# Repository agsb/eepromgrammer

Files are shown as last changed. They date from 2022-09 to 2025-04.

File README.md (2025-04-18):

# EEprogammer

I need a eeprom programmer for use in my projects and want make one
to learn how to wire-wrap.

## Ideas

Based on projects by 
Ben Eater (https://github.com/beneater/eeprom-programmer),
Dave Hovemayer (https://github.com/daveho/eeprog) and 
Tom Nisbet (https://github.com/TomNisbet/TommyPROM)
but with with hardware support for I2C and SPI eeproms.

From above, the following are ok:
        
        - use a Arduino (nano) as main board, with RST, TX and RX reserved;
        - use two 74HC595 for 16-bit address, one for lower byte address, 
                other for uppper byte addres, not chainned
        - use 5 pins for control the both 74HC595
        - use 8 pins for 8-bit data
        - use 2 pins (SDA, SCL) for I2C, WP, S0, S1, S2 to GND, for I2C
        - use 5 pins (/CS, /HOLD, MSCK, MISO, MOSI), WP to VCC, for SPI

From a arduino mini:
        
        - reserved RXD, TXD 
        - using D2 to D9 as data pins
        - using D9 as /HOLD and D10, D11, D12, D13, as SPI

## Pins map

The first design of eeprogrammer was too sensible to errors in 
dip-switches, overrated usability and complex circuit and software, 
then I simply put more headers for other eeprom families;

The reference [Pinout](https://github.com/agsb/eepromgrammer/blob/148cf59fdfdf9b6ff1b859eb0863042efeae660a/PinsOuts.md)

OBS.

I try K.I.S.S.

For all pull-ups using 4k7 resistors.

For all chips VCC - 100nF - GND

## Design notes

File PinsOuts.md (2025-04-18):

## Header Pin Configuration

| Header Pin | Name | Description |
| --- | --- | --- |
| 7 | A14 | Address Pin 14 | 
| 8 | A12 | Address Pin 12 | 
| 9 | A7 | Address Pin 7 | 
| 10 | A6 | Address Pin 6 | 
| 11 | A5 | Address Pin 5 | 
| 12 | A4 | Address Pin 4 | 
| 13 | A3 | Address Pin 3 | 
| 14 | A2 | Address Pin 2 | 
| 15 | A1 | Address Pin 1 | 
| 16 | A0 | Address Pin 0 | 
| 17 | I/O 0 | Data Inputs/Outputs 0 | 
| 18 | I/O 1 | Data Inputs/Outputs 1 | 
| 19 | I/O 2 | Data Inputs/Outputs 2 | 
| 20 | GND | Ground Pin | 

| Header Pin | Name | Description |
| --- | --- | --- |
| 21 | I/O 3 | Data Inputs/Outputs 3 | 
| 22 | I/O 4 | Data Inputs/Outputs 4 | 
| 23 | I/O 5 | Data Inputs/Outputs 5 | 
| 24 | I/O 6 | Data Inputs/Outputs 6 | 
| 25 | I/O 7 | Data Inputs/Outputs 7 | 
| 26 | CE’ | Chip Enable Pin | 
| 27 | A10 | Address Pin 10 | 
| 28 | OE’ | Output Enable | 
| 29 | A11 | Address Pin 11 | 
| 30 | A9 | Address Pin 9 | 
| 31 | A8 | Address Pin 8 | 
| 32 | A13 | Address Pin 13 | 
| 33 | WE’ | Write Enable Pin | 
| 34 | VCC | Supply Voltage Pin | 
| | | |

## Arduino Pin Configuration

| Arduino Pin| circuit | OBS |
| --- | --- | --- |
| D0 | RX | NC, reserved for USART/USB |
| D1 | TX | NC, reserved for USART/USB |
| D2 | D0 | data pin d0 |
| D3 | D1 | data pin d1 |
| D4 | D2 | data pin d2 |
| D5 | D3 | data pin d3 |
| D6 | D4 | data pin d4 |
| D7 | D5 | data pin d5 |
| D8 | D6 | data pin d6 |
| D9 | D7 /HOLD| data pin d7 and SPI /HOLD|
| D10 | /SS RCLK | SPI chip select and serial clock in 74hc595 lower and upper address |
| D11 | MOSI D15 | SPI mosi and extra high address |
| D12 | MISO D16 | SPI miso and extra high address |
| D13 | SCK  D17 | SPI msck and extra high address |
| GND | VSS | board GND |

| Arduino Pin | circuit | OBS |
| --- | --- | --- |
| A0 | /CE | Chip Enable  |
| A1 | /WE | Write Enable |
| A2 | /OE | Output Enable |
| A3 | SRCLR.L | serial clear in 74HC595 lower addres |
| A4 | SDA SRCLR.U | I2C data and serial clear in 74HC595 upper addres |
| A5 | SCL SER.L SER.U | I2C clock and serial in 74HC595 (lower and upper) |

## Pinouts

[Arduino-Nano](https://github.com/agsb/eepromgrammer/blob/e9341a52fbe5ec78b4a520b02f17155613d26bcb/pinout-Arduino-Nano.png)

[SN74HC595](https://github.com/agsb/eepromgrammer/blob/b177c6ecdc0a47e471f062eab4fed304ac8fa284/pinout-74hc595.png)

[AT28C256](https://github.com/agsb/eepromgrammer/blob/e9341a52fbe5ec78b4a520b02f17155613d26bcb/pinout-AT28C256.jpg)

[AT28C64](https://github.com/agsb/eepromgrammer/blob/e9341a52fbe5ec78b4a520b02f17155613d26bcb/pinout-AT28C64.jpg)

[AT28C16](https://github.com/agsb/eepromgrammer/blob/e9341a52fbe5ec78b4a520b02f17155613d26bcb/pinout-AT28C16.png)

[SST39SF040](https://github.com/agsb/eepromgrammer/blob/e9341a52fbe5ec78b4a520b02f17155613d26bcb/pinout-SST39SF040.png)

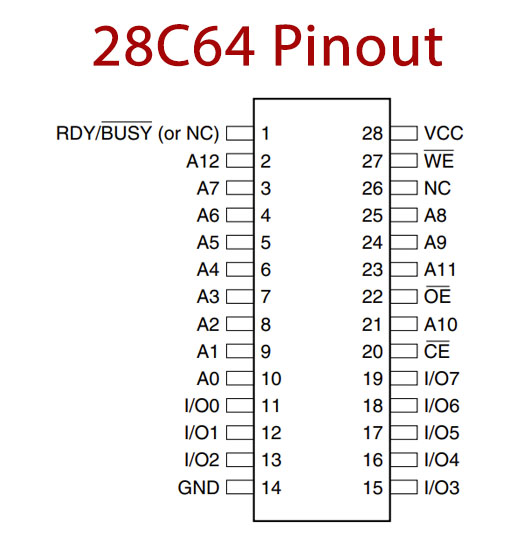
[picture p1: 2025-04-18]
pinout-AT28C64.jpg

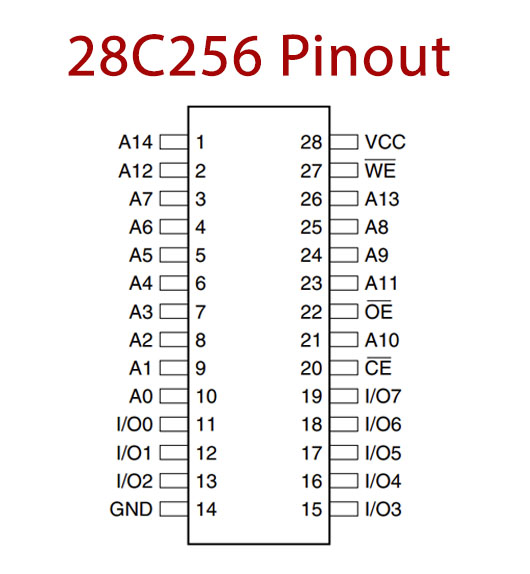
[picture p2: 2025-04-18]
pinout-AT28C256.jpg

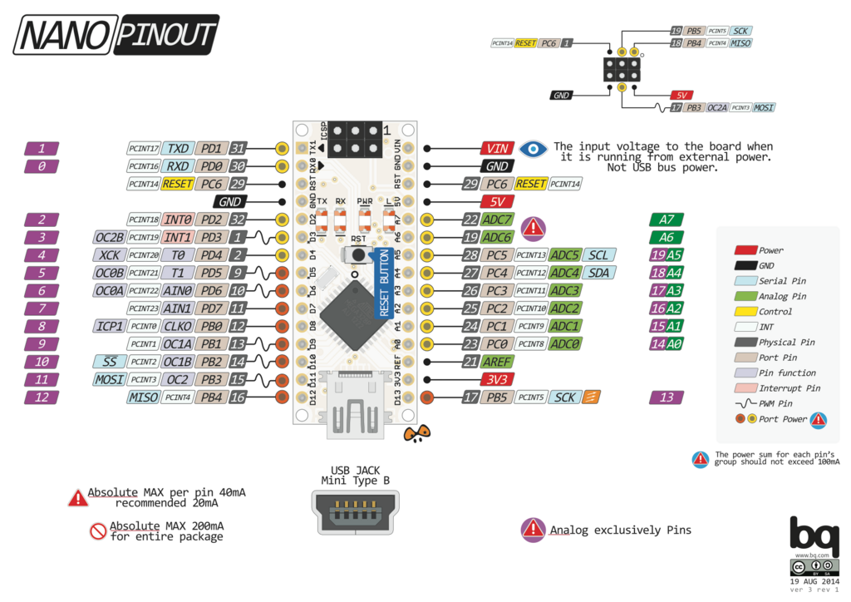
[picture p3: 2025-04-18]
pinout-Arduino-Nano.png

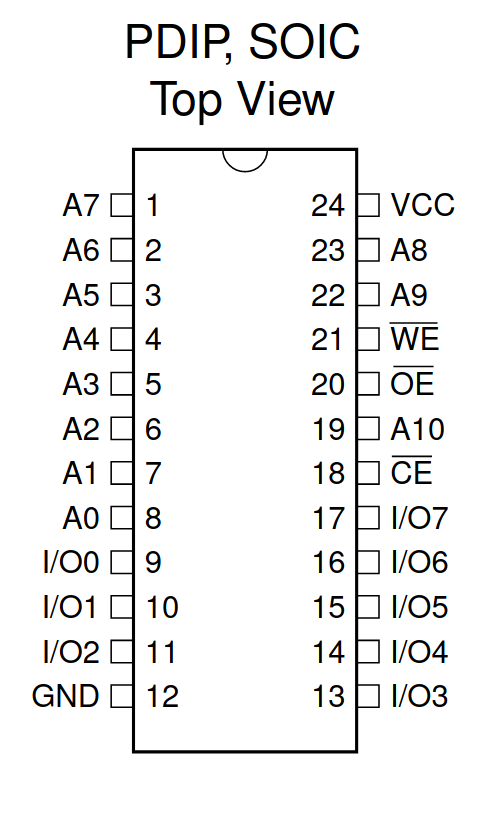
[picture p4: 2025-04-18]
pinout-AT28C16.png

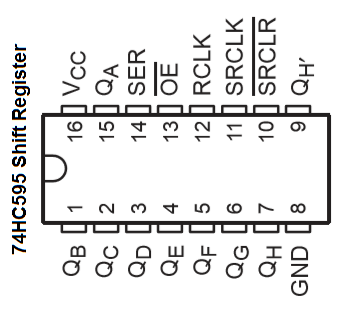
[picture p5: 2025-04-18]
pinout-74hc595.png

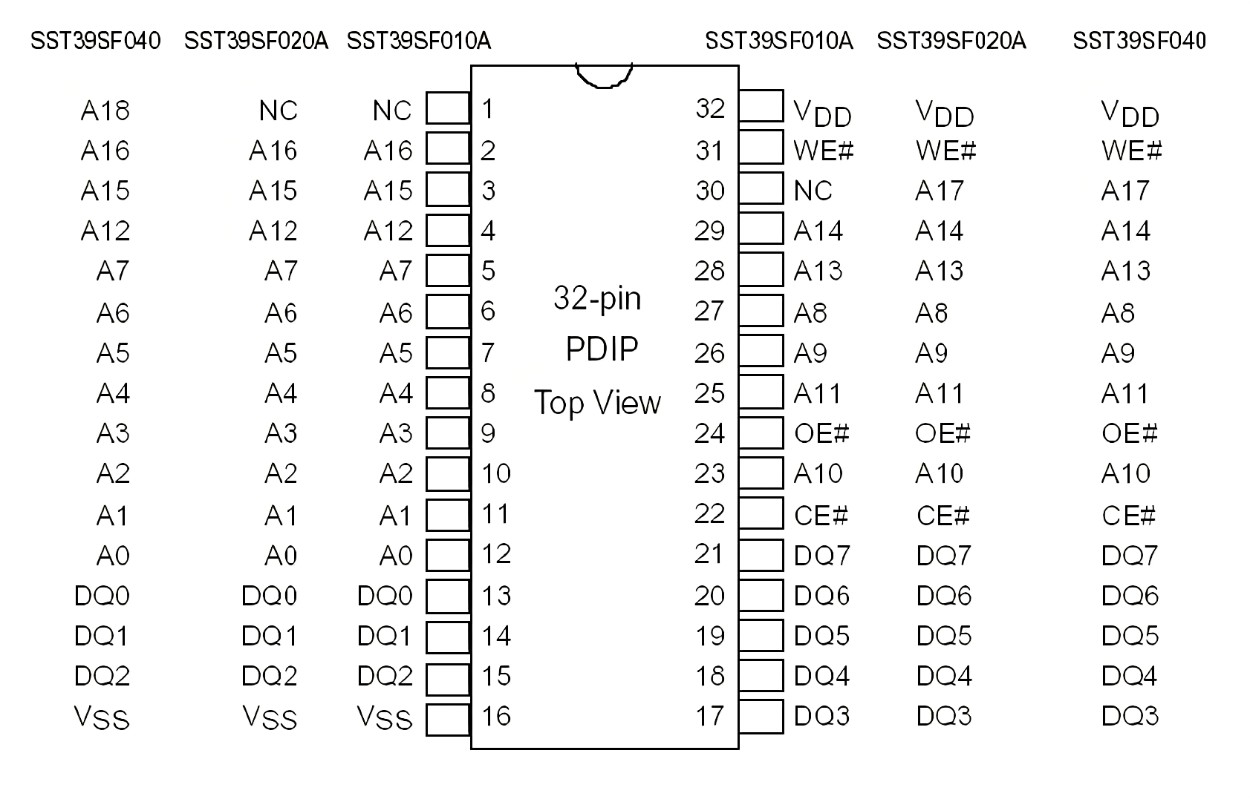
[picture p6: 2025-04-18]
pinout-SST39SF040.png

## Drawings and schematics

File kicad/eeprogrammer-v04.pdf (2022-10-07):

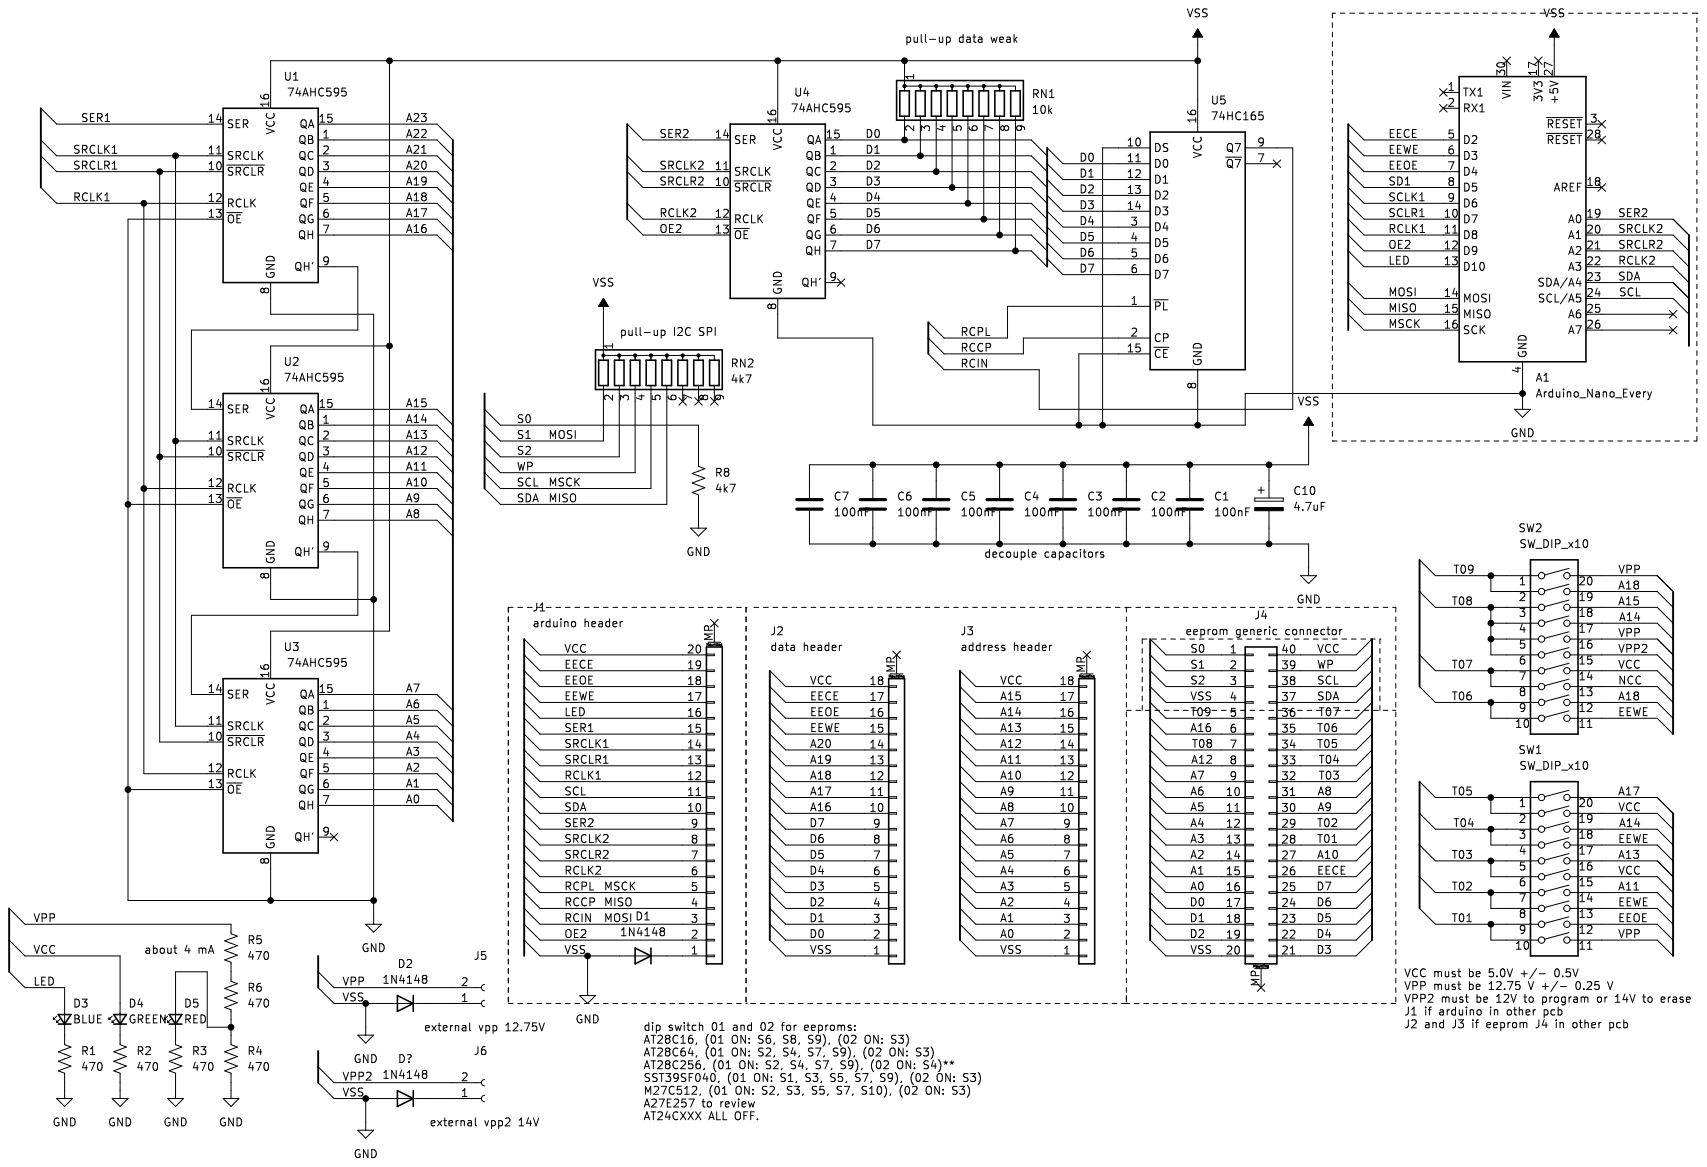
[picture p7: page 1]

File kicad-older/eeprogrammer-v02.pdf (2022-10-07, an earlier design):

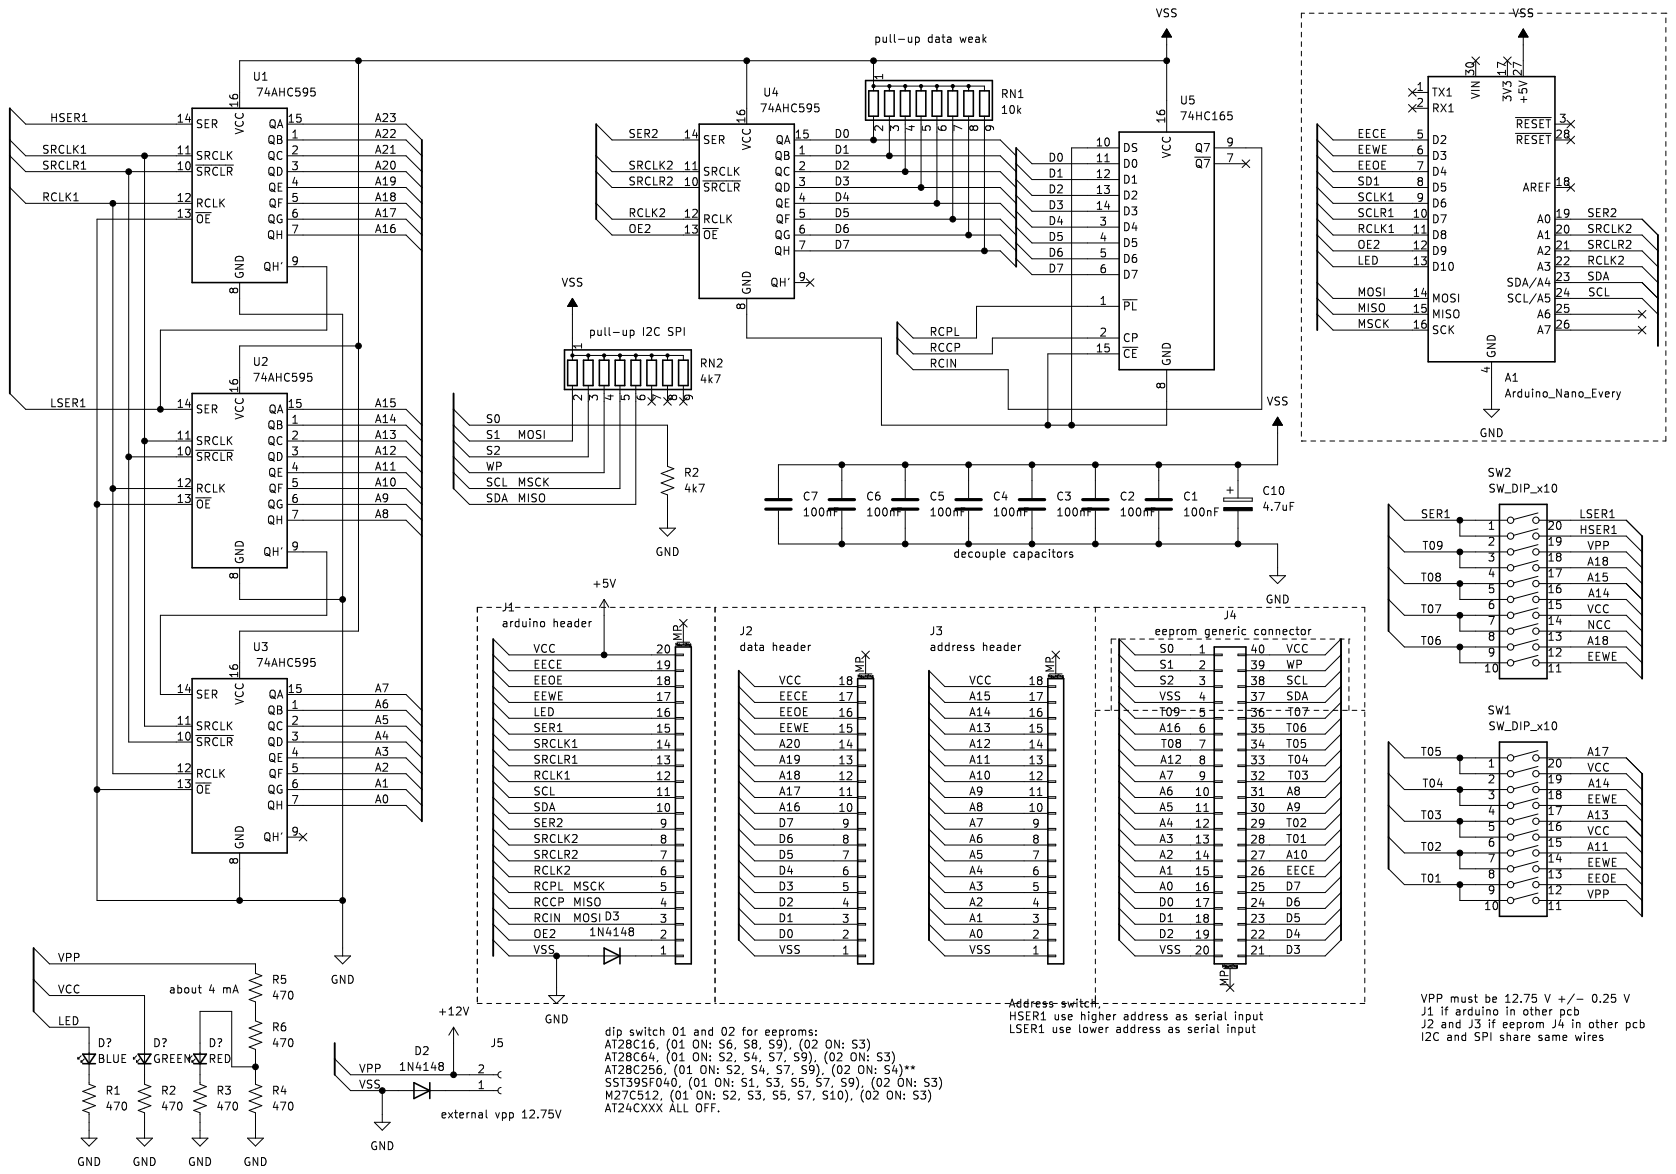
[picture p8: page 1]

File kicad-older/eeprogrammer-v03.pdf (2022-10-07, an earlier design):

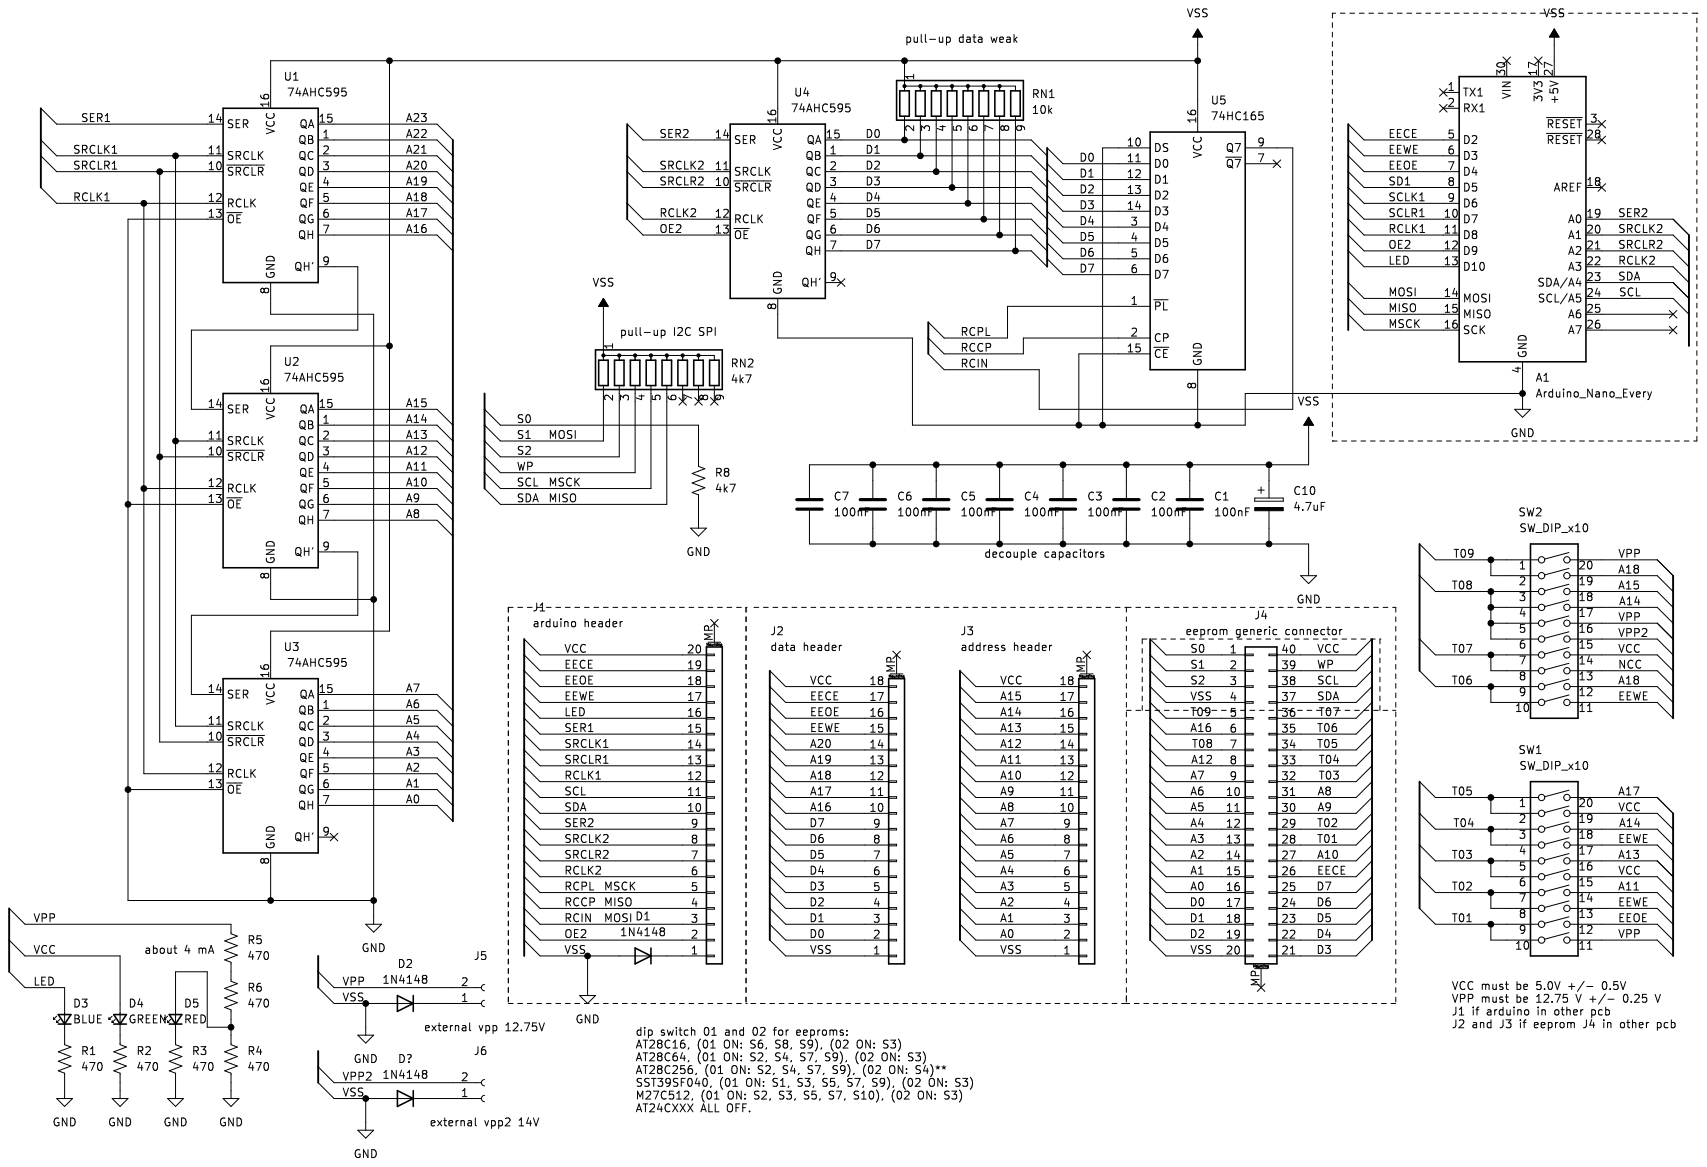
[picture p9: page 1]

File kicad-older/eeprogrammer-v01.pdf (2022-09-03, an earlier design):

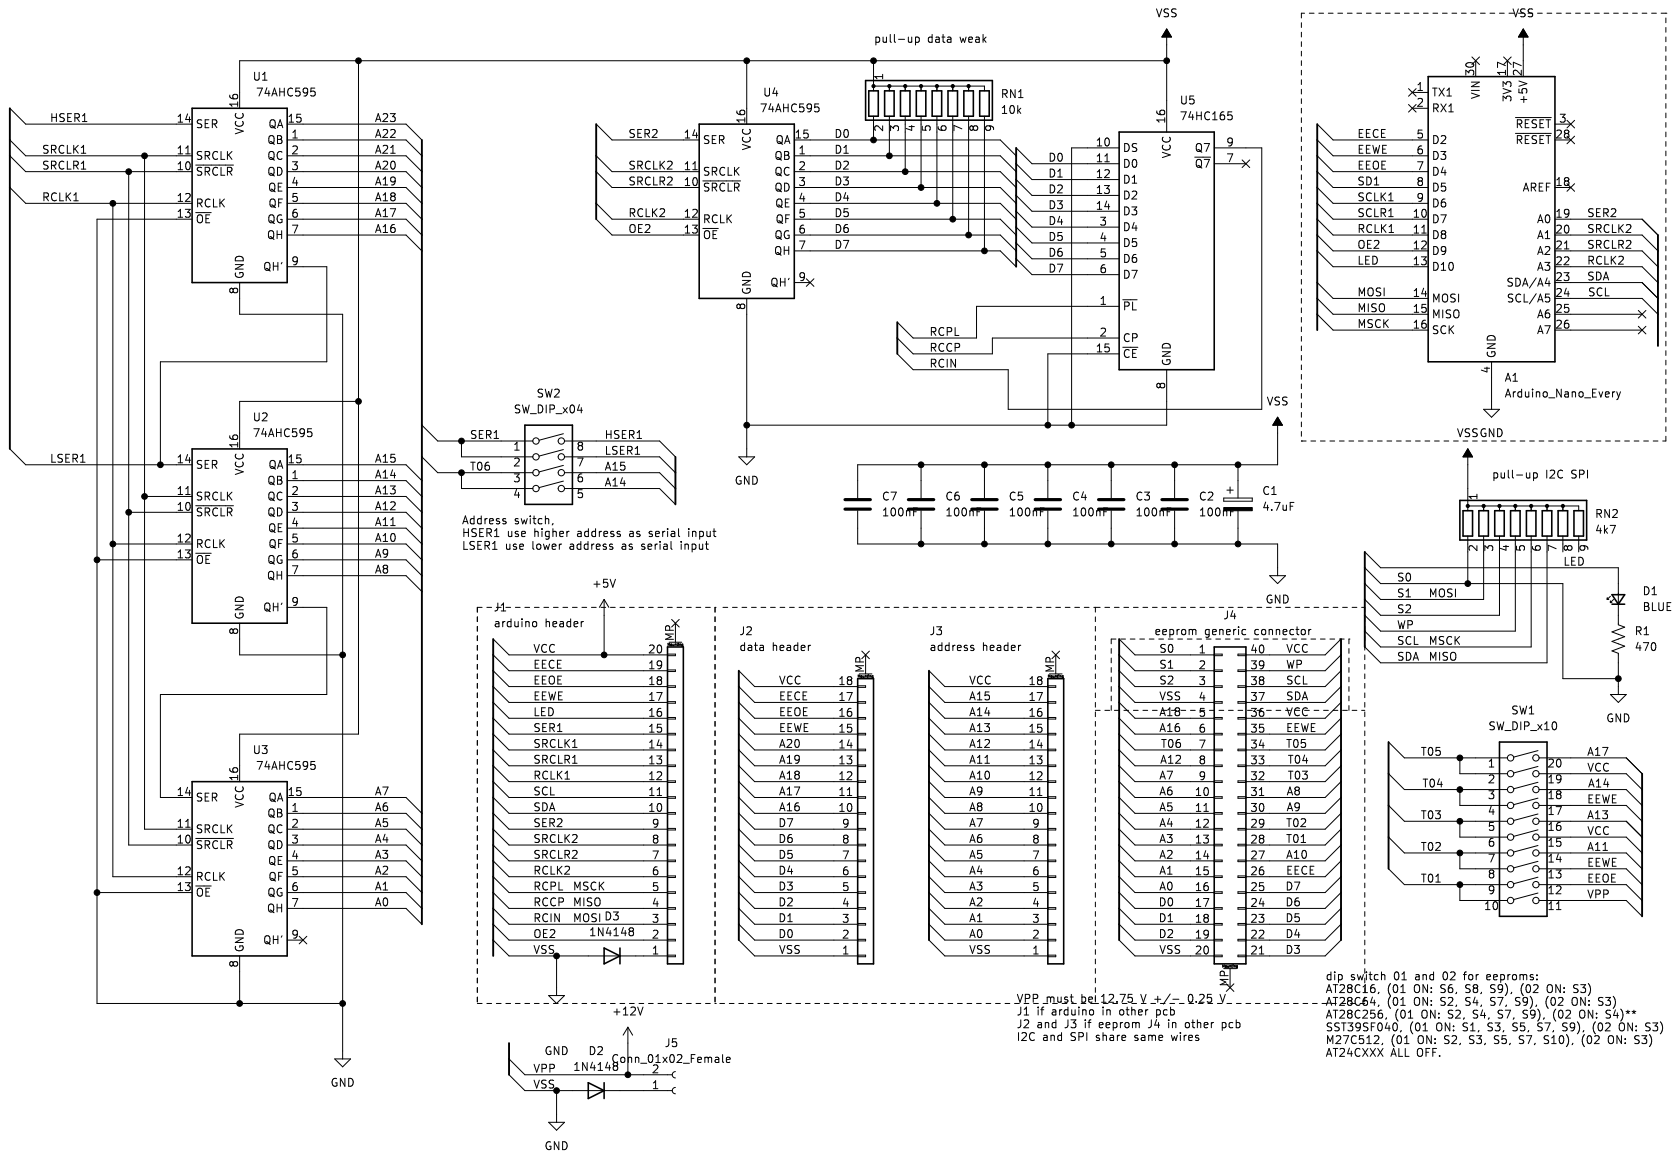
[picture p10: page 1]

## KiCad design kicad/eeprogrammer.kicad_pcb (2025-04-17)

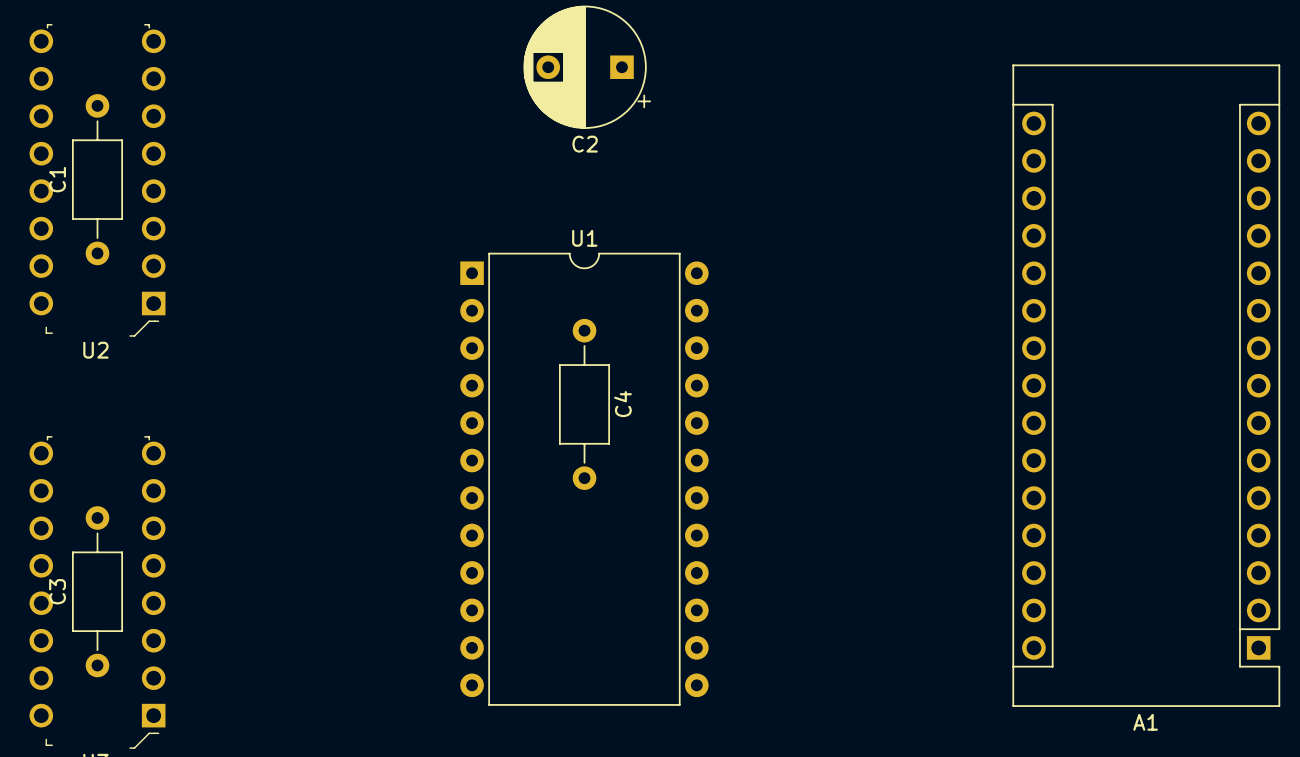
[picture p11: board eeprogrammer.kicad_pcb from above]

Board: 2 copper layers, 8 parts (0 on the bottom side), 30 nets, no tracks yet.

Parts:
A1: Arduino_Nano_v2.x; Arduino_Nano
C1, C3, C4: C; C_Axial_L5.1mm_D3.1mm_P10.00mm_Horizontal
C2: C_Polarized; CP_Radial_D8.0mm_P5.00mm
U1: 28C16; DIP-24_W15.24mm
U2, U3: 74HC595; DIP-16_W7.62mm

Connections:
GND: A1.4 (GND), A1.29 (GND), C1.2, C2.2, C3.2, C4.2, U1.12 (GND), U2.8 (GND), U3.8 (GND)
unnamed: A1.5 (D2), U1.9 (D0)
unnamed: A1.6 (D3), U1.10 (D1)
unnamed: A1.7 (D4), U1.11 (D2)
unnamed: A1.8 (D5), U1.13 (D3)
unnamed: A1.9 (D6), U1.14 (D4)
unnamed: A1.10 (D7), U1.15 (D5)
unnamed: A1.11 (D8), U1.16 (D6)
unnamed: A1.12 (D9), U1.17 (D7)
unnamed: A1.13 (D10), U1.18 (~CS)
unnamed: A1.14 (D11), U1.20 (~OE)
unnamed: A1.15 (D12), U1.21 (~WE)
unnamed: A1.19 (A0), U2.14 (SER)
unnamed: A1.20 (A1), U2.11 (SRCLK), U3.11 (SRCLK)
unnamed: A1.21 (A2), U2.10 (~SRCLR), U3.10 (~SRCLR)
unnamed: A1.22 (A3), U2.12 (RCLK), U3.12 (RCLK)
unnamed: A1.23 (A4), U2.13 (~OE), U3.13 (~OE)
unnamed: U1.7 (A1), U2.1 (QB)
unnamed: U1.6 (A2), U2.2 (QC)
unnamed: U1.5 (A3), U2.3 (QD)
unnamed: U1.4 (A4), U2.4 (QE)
unnamed: U1.3 (A5), U2.5 (QF)
unnamed: U1.2 (A6), U2.6 (QG)
unnamed: U1.1 (A7), U2.7 (QH)
unnamed: U2.9 (QH'), U3.14 (SER)
unnamed: U1.8 (A0), U2.15 (QA)
unnamed: U1.19 (A10), U3.2 (QC)
unnamed: U1.22 (A9), U3.1 (QB)
unnamed: U1.23 (A8), U3.15 (QA)
VCC: A1.27 (+5V), C1.1, C2.1, C3.1, C4.1, U1.24 (VCC), U2.16 (VCC), U3.16 (VCC)

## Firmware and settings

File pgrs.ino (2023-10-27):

/**
 * ** project Arduino EEPROM programmer **
 * 
 * This sketch can be used to read and write data to a
 * AT28C64 or AT28C256 parallel EEPROM
 *
 * $Author: mario, edited by Zack $
 * $Date: 2013/05/05 11:01:54 $
 * $Revision: 1.3 $
 *
 * This software is freeware and can be modified, reused or thrown away without any restrictions.
 *
 * Use this code at your own risk. I'm not responsible for any bad effect or damages caused by this software!!!
 *
 **/

#define VERSIONSTRING "MEEPROMMER $Revision: 1.3 $ $Date: 12/18/2013 15:56:00 $, CMD:R,r,w,W,V, u"

// shiftOut part
#define PORTC_DS      0
#define PORTC_LATCH   1
#define PORTC_CLOCK   2

// eeprom IO lines:D0-D7 = pins2-9

// IO lines for the eeprom control
#define PORTC_CE   3
#define PORTC_OE   4
#define PORTC_WE   5

//a buffer for bytes to burn
#define BUFFERSIZE 1024 
byte buffer[BUFFERSIZE];
//command buffer for parsing commands
#define COMMANDSIZE 16
char cmdbuf[COMMANDSIZE];

unsigned int startAddress,endAddress;
unsigned int lineLength,dataLength;

//define COMMANDS
#define NOCOMMAND    0
#define VERSION      1

#define READ_HEX    10
#define READ_BIN    11

#define WRITE_PAGE  20
#define WRITE_BIN   21

#define UNLOCK      30

/*****************************************************************
 *
 *  CONTROL and DATA functions
 *
 ****************************************************************/

void data_bus_input(){
  DDRD &= 0b00000011;
  DDRB &= 0b11111100;
}

void data_bus_output(){
  DDRD |= 0b11111100;
  DDRB |= 0b00000011;
}

byte read_data_bus(){
  return ((PINB<<6)|(PIND>>2));
}

void write_data_bus(byte data){
  PORTB &= 0b11111100;  
  PORTB |= (data>>6);
  PORTD &= 0b00000011;
  PORTD |= (data<<2);
}

//shift out the given address to the 74hc595 registers
void set_address_bus(unsigned int address){
  bitClear(PORTC,PORTC_LATCH);		//disable latch line
  fastShiftOut(highByte(address));	//shift out highbyte
  fastShiftOut(lowByte(address));	//shift out lowbyte
  bitSet(PORTC,PORTC_LATCH);		//enable latch and set address
}

void fastShiftOut(byte data){
  for(int i=7; i>=0; i--){//shift MSB first
    //clear data pin after shift to prevent bleed through
    bitClear(PORTC,PORTC_DS);
    bitClear(PORTC,PORTC_CLOCK);
    if(bitRead(data,i))bitSet(PORTC,PORTC_DS);
    //register shifts bits on rising clock
    bitSet(PORTC,PORTC_CLOCK);
  }
  bitClear(PORTC,PORTC_CLOCK);
}

byte read_byte(unsigned int address){
  data_bus_input();			//set databus for reading
  bitClear(PORTC,PORTC_CE);	//enable chip select
  bitSet(PORTC,PORTC_WE);	//disable write
  set_address_bus(address);	//set address bus
  bitClear(PORTC,PORTC_OE);	//enable output
  //delay 312.5ns @ 16MHz
  __asm__("nop\n\t""nop\n\t""nop\n\t""nop\n\t""nop\n\t");
  byte data = read_data_bus();
  bitSet(PORTC,PORTC_OE);	//disable output
  bitSet(PORTC,PORTC_CE);	//enable chip select
  return data;
}

void fast_write(unsigned int address, byte data){
  bitSet(PORTC,PORTC_OE);	//first disable output
  bitSet(PORTC,PORTC_WE);	//disable write
  set_address_bus(address);	//set address bus
  data_bus_output();		//set databus to output
  write_data_bus(data);		//set data bus
  bitClear(PORTC,PORTC_CE);	//enable chip select
  bitClear(PORTC,PORTC_WE);	//enable write
  __asm__("nop\n\t""nop\n\t");  //delay 125ns @ 16MHz
  bitSet(PORTC,PORTC_WE);	//disable write
  data_bus_input();
  bitClear(PORTC,PORTC_OE);
  //delay 312.5ns @ 16MHz
  __asm__("nop\n\t""nop\n\t""nop\n\t""nop\n\t""nop\n\t");
  while(data != read_data_bus()); //poll data
  bitSet(PORTC,PORTC_OE);
  bitSet(PORTC,PORTC_CE);
}

void write_block_page(unsigned int address, byte* buffer, int len, int page){
  address &= ~(page-1);	//address must not break page boundaries
  bitSet(PORTC,PORTC_WE);	//disable write
  bitClear(PORTC,PORTC_CE);	//enable chip
  for(int n=0; n<len/page; n++){
    bitSet(PORTC,PORTC_OE);
    data_bus_output();		//set databus to output
    for(unsigned int i=n*page; i<(n+1)*page; i++){
      bitSet(PORTC,PORTC_WE);		//disable write
      set_address_bus(address+i);	//set address bus
      write_data_bus(buffer[i]);	//set data bus
      bitClear(PORTC,PORTC_WE);		//enable write
      //100ns+ tWP delay caused by for looping
    }
    bitSet(PORTC,PORTC_WE);		//write must be high for tBLC(100us)
    data_bus_input();
    bitClear(PORTC,PORTC_OE);	//enable output
    //delay 312.5ns @ 16MHz
    __asm__("nop\n\t""nop\n\t""nop\n\t""nop\n\t""nop\n\t");
    while(buffer[(n+1)*page-1] != read_data_bus()); //poll data
  }
  bitSet(PORTC,PORTC_CE);
}

/************************************************
 *
 * COMMAND and PARSING functions
 *
 *************************************************/

void readCommand(){
  int idx = 0;
  do {//read 'til linebreak or buffer is full
    if(Serial.available())cmdbuf[idx++] = Serial.read();
  } while (cmdbuf[idx-1] != '\n' && idx < COMMANDSIZE);
  for(;idx<COMMANDSIZE;idx++)cmdbuf[idx] = 0;//clear the rest of command buffer 
}

byte parseCommand(){
  //command format:C AAAA DDDD LL
  startAddress=hexWord(cmdbuf+2);	//A
  dataLength=hexWord(cmdbuf+7);	//D
  lineLength=hexByte(cmdbuf+12);	//L
  switch(cmdbuf[0]){
  case 'R':
    return(READ_HEX);
  case 'r':
    return(READ_BIN);
  case 'W':
    return(WRITE_PAGE);
  case 'w': 
    return(WRITE_BIN);
  case 'V':
    return(VERSION);
  case 'u':
    return(UNLOCK);
  default:
    return(NOCOMMAND);
  }
}

byte hexDigit(char c){ //ascii char to value
  if(c >= '0' && c <= '9')return c - '0';
  if(c >= 'a' && c <= 'f')return c - 'a' + 10;
  if(c >= 'A' && c <= 'F')return c - 'A' + 10;
  return 0;// getting here is bad: it means the character was invalid
}

byte hexByte(char* a){ //ascii byte to value
  return ((hexDigit(a[0])<<4) | hexDigit(a[1]));
}

//ascii word to value
unsigned int hexWord(char* data){
  return ((hexDigit(data[0])<<12)|
    (hexDigit(data[1])<<8)|
    (hexDigit(data[2])<<4)|
    (hexDigit(data[3]))); 
}


/************************************************
 *
 * INPUT / OUTPUT Functions
 *
 *************************************************/

void read_block(unsigned int from, unsigned int to, int linelength){
  int outcount = 0;
  //loop from "from address" to "to address" (included)
  for(unsigned int address = from; address <= to; address++){
    if(outcount == 0){
      //print out the address at the beginning of the line
      Serial.println();
      Serial.print("0x");
      printAddress(address);
      Serial.print(" : ");
    }
    //print data, separated by a space
    printByte(read_byte(address));
    Serial.print(" ");
    outcount = (++outcount % linelength);
  }
  Serial.println();
}

void read_binblock(unsigned int from, unsigned int to){
  for(unsigned int address = from; address <= to; address++){
    Serial.write(read_byte(address));
  }
  Serial.print('\0');//success return code
}  

void write_block(unsigned int address, byte* buffer, int len){
  for(unsigned int i = 0; i < len; i++){
    fast_write(address+i,buffer[i]);
  }   
}

void printAddress(unsigned int address){
  if(!(address & 0xfff0)) Serial.print("0");
  if(!(address & 0xff00)) Serial.print("0");
  if(!(address & 0xf000)) Serial.print("0");
  Serial.print(address, HEX);
}

void printByte(byte data){
  if(!(data & 0xf0)) Serial.print("0");
  Serial.print(data, HEX);  
}


/************************************************
 *
 * MAIN
 *
 *************************************************/
void setup(){
  DDRC = 0b00111111;	//set EEPROM & shiftOut Pins as output
  PORTC = 0b00111000;	//set EEPROM Pins high
  //Serial.begin(57600);	//set speed of serial connection
  Serial.begin(115200);
}

void loop(){
  int bytes = 0;
  readCommand();
  switch(parseCommand()){
  case READ_HEX:
    if(lineLength==0) lineLength=32; //default
    endAddress = startAddress + dataLength -1;
    read_block(startAddress,endAddress,lineLength);
    Serial.println('%');//success return code
    break;
  case READ_BIN:
    endAddress = startAddress + dataLength -1;
    read_binblock(startAddress,endAddress);
    break;
  case WRITE_PAGE:
    if(dataLength > 1024) dataLength = 1024;
    while(bytes < dataLength)if(Serial.available())buffer[bytes++] = Serial.read();
    if(lineLength==0) lineLength=32; //page size
    write_block_page(startAddress,buffer,dataLength,lineLength);
    Serial.println('%');
    break;
  case WRITE_BIN:
    if(dataLength > 1024) dataLength = 1024; //1024 is max
    while(bytes < dataLength)if(Serial.available())buffer[bytes++] = Serial.read();
    write_block(startAddress,buffer,dataLength);
    Serial.println('%');
    break;
  case VERSION:
    Serial.println(VERSIONSTRING);
    break;
  case UNLOCK:
    fast_write(0x5555,0xAA);
    fast_write(0x2AAA,0x55);
    fast_write(0x5555,0x80);
    fast_write(0x5555,0xAA);
    fast_write(0x2AAA,0x55);
    fast_write(0x5555,0x20);
    Serial.print('%');//success return code
    break;
  }
}

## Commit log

2022-09-03 kicad files
    [eepromgramer.kicad_pcb, eepromgramer.kicad_sch]
2025-04-17 better easy
    [eeprogram.chips.kicad_sch, eeprogram.detail.pins.kicad_sch, eeprogrammer.kicad_pcb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]
2025-04-19 proto wire-wrap squema
2025-04-19 update wire-wrap list script
2025-04-20 does wire-wraps list sorted
2025-05-29 update schematics
    [eeprogram.chips.kicad_sch]
2025-05-30 update wire list
    [eeprogram.chips.kicad_sch, eeprogrammer.kicad_sch]
